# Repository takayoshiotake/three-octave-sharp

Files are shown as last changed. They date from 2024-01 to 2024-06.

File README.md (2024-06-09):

# Three Octave \#

[][cc-by-sa]

A 38-key (3-octave + 1) keyboard. Powered by [Vial](https://get.vial.today/) firmware.

This keyboard is based on a 60% column staggered keyboard like the HHKB, which omits the number and symbol keys to reduce the number of keys to 38.

## Layout

v0.3.0

**Layer 0**:

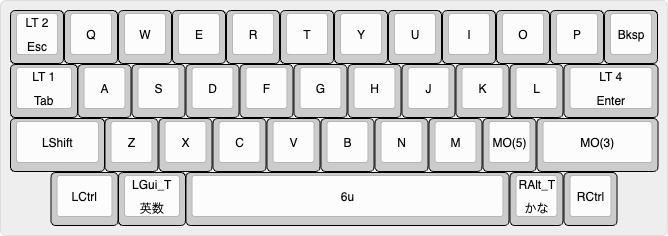
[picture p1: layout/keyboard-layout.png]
keyboard layout


MEMO: I couldn't figure out how to map keys to `fn` on macOS using Vial, so I am using Karabiner-Elements, a macOS app, to modify `right_control` to `fn`.

**Layer 1, 2**: arrows, symbols

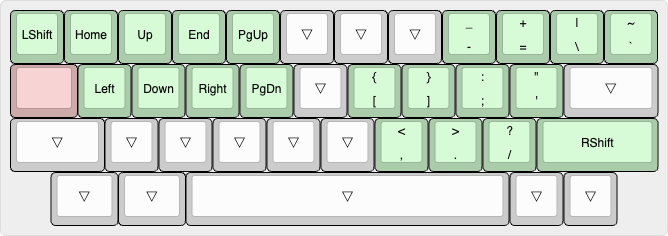
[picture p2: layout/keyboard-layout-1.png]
keyboard layout 1

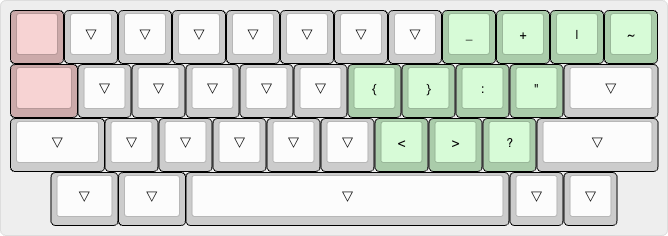
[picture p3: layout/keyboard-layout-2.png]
keyboard layout 2


**Layer 3, 4**: nums, symbols

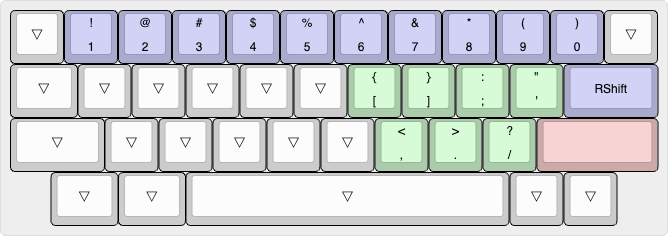
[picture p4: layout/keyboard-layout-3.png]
keyboard layout 3

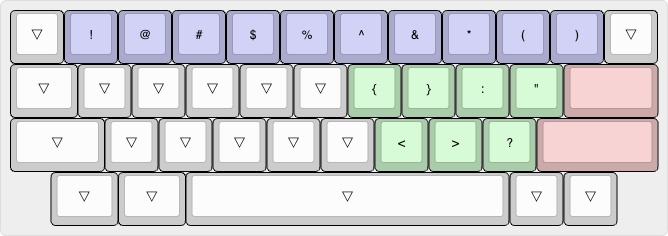
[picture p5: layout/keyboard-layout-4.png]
keyboard layout 4


**Layer 5**: fn

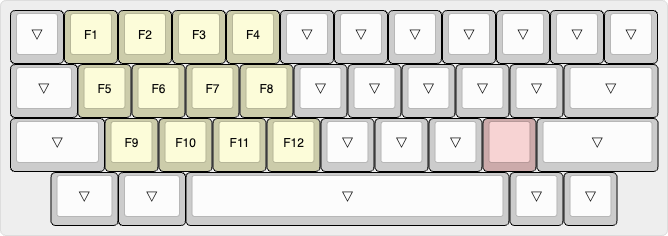
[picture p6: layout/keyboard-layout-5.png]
keyboard layout 5


**RAW data for Keyboard Layout Editor v0.15:**

📄 [keyboard-layout.rawdata.json](layout/keyboard-layout.rawdata.json)

```json
[{a:1},"LT 2\nEsc",{a:7},"Q","W","E","R","T","Y","U","I","O","P","Bksp"],
[{a:1,w:1.25},"LT 1\nTab",{a:7},"A","S","D","F","G","H","J","K","L",{a:1,w:1.75},"LT 4\nEnter"],
[{a:7,w:1.75},"LShift","Z","X","C","V","B","N","M","MO(5)",{w:2.25},"MO(3)"],
[{x:0.75,w:1.25},"LCtrl",{a:1,w:1.25},"LGui_T\n英数",{a:7,w:6},"6u",{a:1},"RAlt_T\nかな",{a:7},"RCtrl"],
```

- 🔗 [Keyboard Layout Editor](http://www.keyboard-layout-editor.com/)

## BOM

| Material | QTY | Note |
|-|-:|-|
| Three Octave Sharp PCBA | 1 | |
| Three Octave Sharp Case | 1 | |
| B-0204 | 4 | Screw M2 L4, Hirosugi |
| SIS-2039-05 | 4 | Washer d2 D3.9 t0.5, Hirosugi |
| LUW-0204-075 | 4 | Washer d2.2 D4 t0.075, Hirosugi |

### Three Octave Sharp PCBA

| Material | Symbol | QTY | Note |
|-|-|-:|-|
| Three Octave Sharp PCB | - | 1 | |
| 30pF 402 | C1, C2 | 2 | C1570 |
| 1uF 402 | C3, C4 | 2 | C52923 |
| 100nF 402 | C5-C14 | 10 | C307331 |
| 10uF 402 | C15, C16 | 2 | C15525 |
| HRO_TYPE-C-31-M-12 | J1 | 1 | C165948; USB Type-C Connector, Korean Hroparts Elec |
| 10KΩ 0402 | R1, R3 | 2 | C25744 |
| 1KΩ 0402 | R2, R4 | 2 | C11702 |
| 27Ω 0402 | R5, R6 | 2 | C352446 |
| 5.1KΩ 0402 | R7, R8 | 2 | C25905 |
| Hot_Swap_Socket_CPG151101S11 | SW1-SW38 | 38 | C5156480; How Swap Socket, Kailh |
| SKRPANE010 | SW_B1, SW_R1 | 2 | C470426; Tactile Switch, ALPS ALPINE |
| RP2040 | U1 | 1 | C2040; MCU, Raspberry Pi |
| W25Q64JVXGIQ | U2 | 1 | C2940195, 64M-bit Serial Flash, Winbond Electronics |
| AP2112K-3.3TRG1 | U3 | 1 | C51118, 3.3V Linear Voltage Regulators |
| X322512MSB4SI | Y1 | 1 | C9002, 12MHz 20pF Crystal Resonator, SMD-3225, Yangxing Tech |

📁 [production_data (for JLCPCB at 2024-01-25)](electronics/Three_Octave_Sharp/production/Three_Octave_Sharp_1.0.0_2024-01-25_19-34-58)

### Three Octave Sharp Case

WIP

## Schematic and PCB

📄 [Three_Octave_Sharp.kicad_sch](electronics/Three_Octave_Sharp/Three_Octave_Sharp.kicad_sch) (v1.0.0)

📄 [Three_Octave_Sharp.kicad_pcb](electronics/Three_Octave_Sharp/Three_Octave_Sharp.kicad_pcb) (v1.0.1)

schematic svg

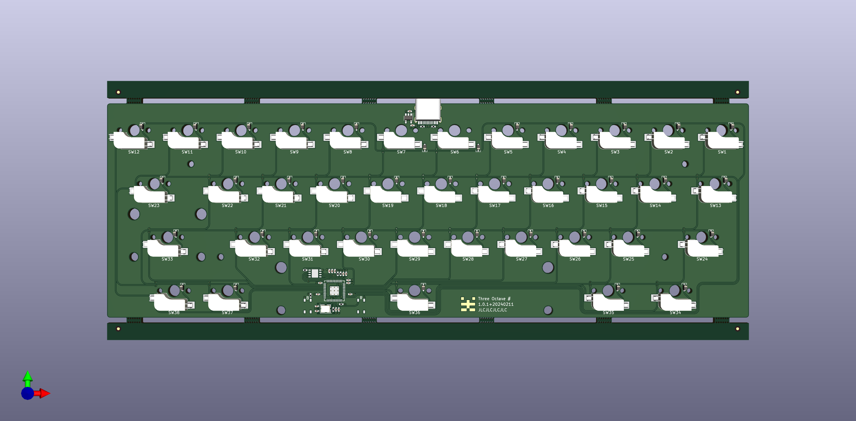
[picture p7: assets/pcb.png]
pcb png


### Key-matrix

| | C0 | C1 | C2 | C3 | C4 | C5 | C6 | C7 | C8 | C9 | C10 | C11 |
|----|---|---|---|----|----|----|----|----|----|---|---|-----|
| R0 | Esc | Q | W | E  | R  | T  | Y  | U  | I  | O | P | BS  |
| R1 | Tab | A | S | D  | F  | G  | H  | J  | K  | L | Return | |
| R2 | Shift | Z | X | C  | V  | B  | N  | M  | ,  | Shift | Opt | Fn  | 
| R3 | Ctrl  | Cmd  | Space | | | | | | | | | |

## Mechanics

The case also functions as a plate.

- 📄 [Three-Octave-Sharp-Case.FCStd](mechanics/Three-Octave-Sharp-Case.FCStd) (v1.0.3)
    - 📄 [Three-Octave-Sharp-Case-Top.step](mechanics/Three-Octave-Sharp-Case-Top.step)
    - 📄 [Three-Octave-Sharp-Case-Bottom.step](Three-Octave-Sharp-Case-Bottom.step)

<div style="display: grid; gap: 1px; grid-template: 'a0 a0 a0 a0' 'a2t a2t a2b a2b' 'a5t a5t a5b a5b' 'a1 a3 a4 a6';">
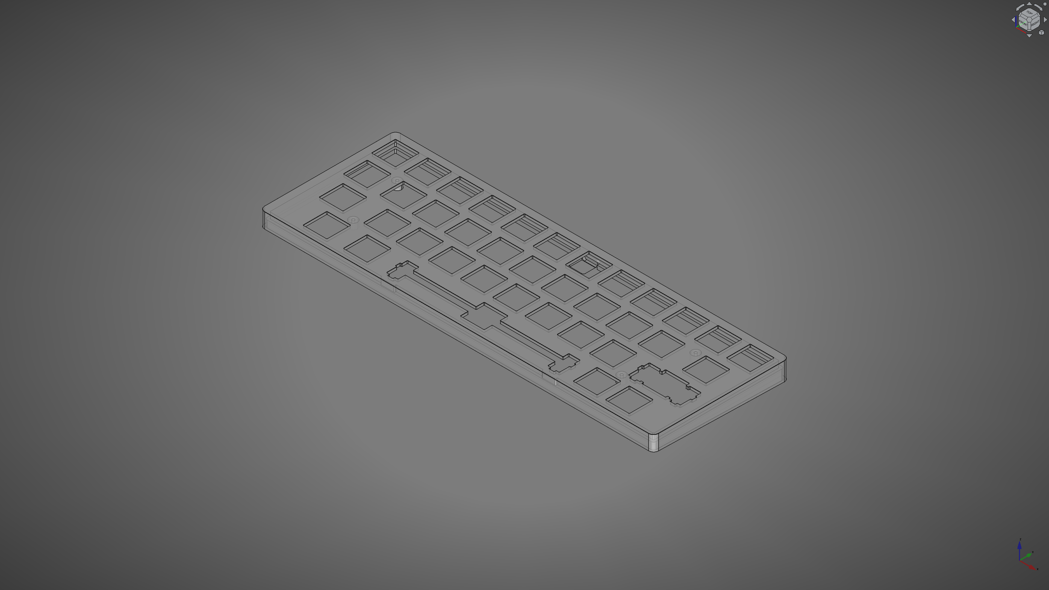
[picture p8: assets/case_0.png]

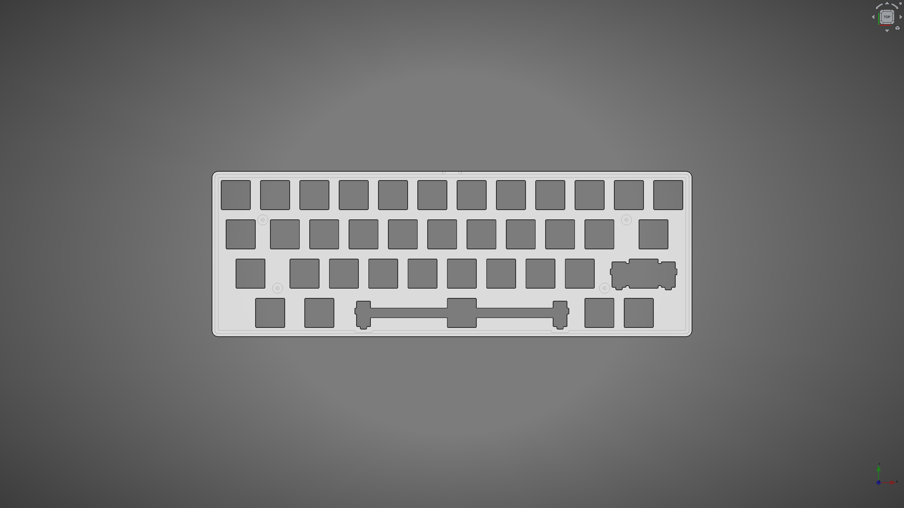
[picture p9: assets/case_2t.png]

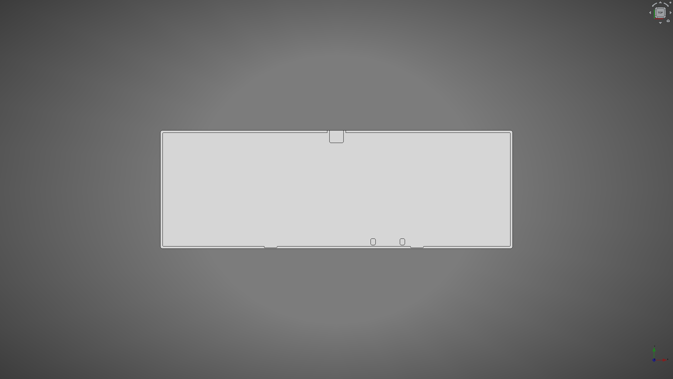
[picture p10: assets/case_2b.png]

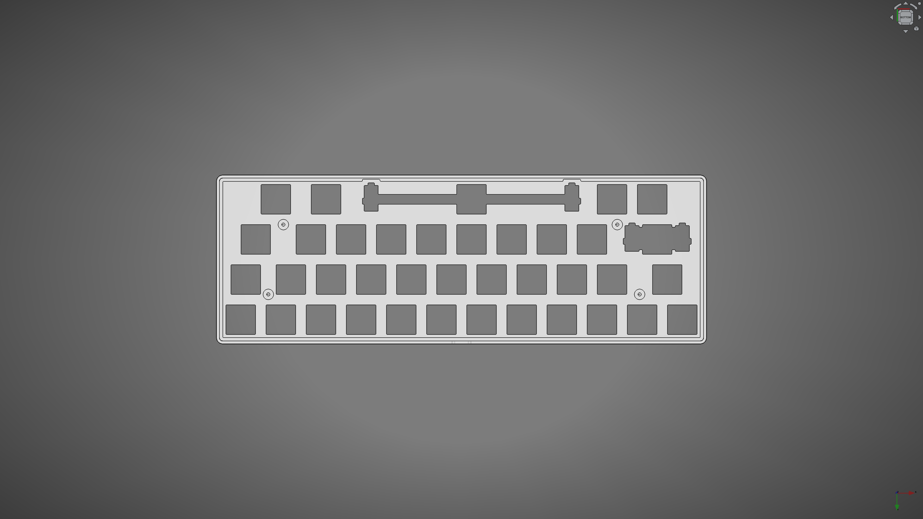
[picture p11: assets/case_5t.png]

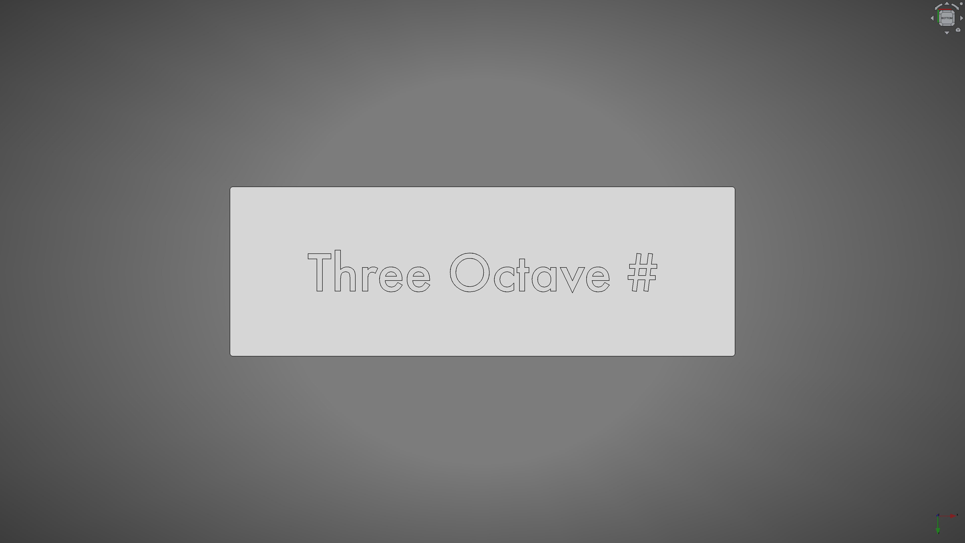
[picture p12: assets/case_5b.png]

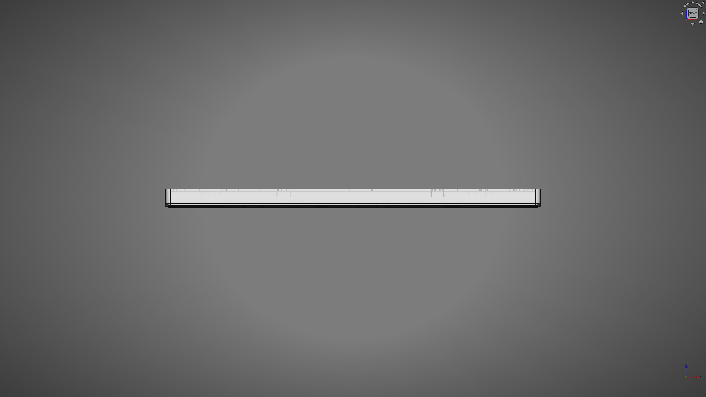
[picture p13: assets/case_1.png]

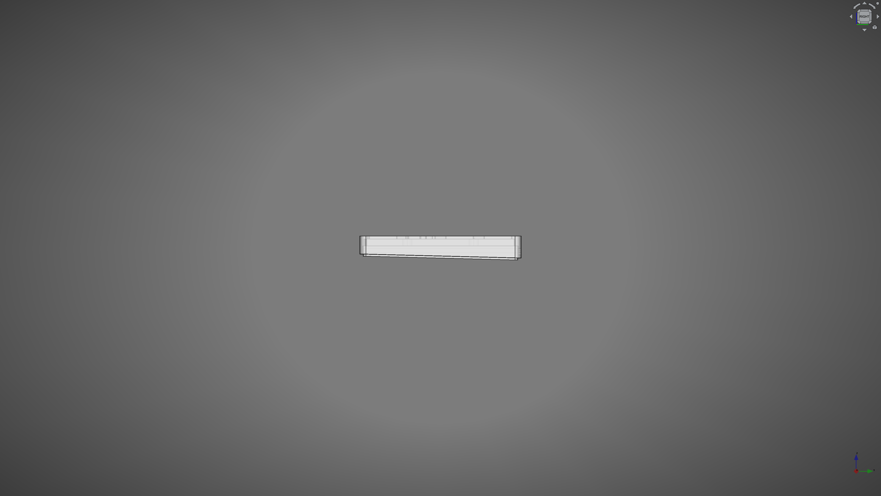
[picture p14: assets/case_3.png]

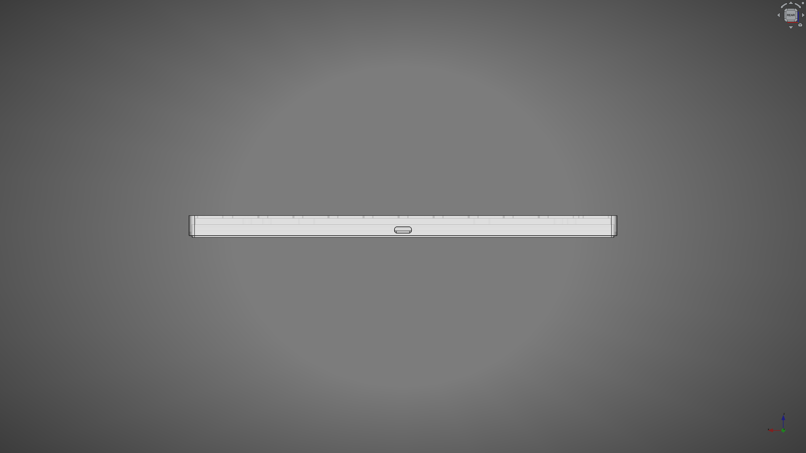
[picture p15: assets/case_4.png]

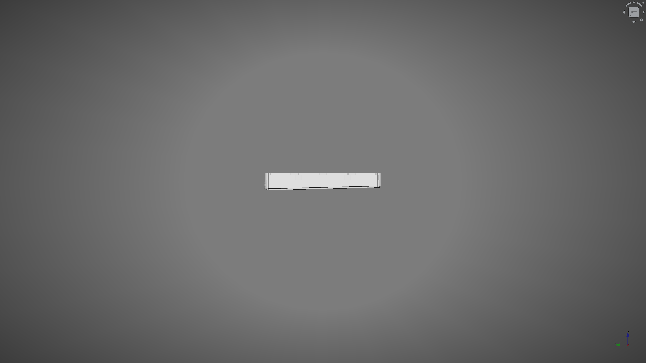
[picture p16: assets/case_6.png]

</div>

## Firmware

### Vial

- Built UF2
    - 📄 [takayoshiotake_three_octave_sharp_vial_20240407.uf2](vial-bin/takayoshiotake_three_octave_sharp_vial_20240407.uf2)
- Code
    - 🔗 <https://github.com/vial-kb/vial-qmk/tree/vial/keyboards/takayoshiotake/three_octave_sharp>
    - 🔗 <https://github.com/vial-kb/vial-qmk/tree/bbaed80505cf4ceaeb51d1e5fe79b23b22acf1a6>

See [vial-porting](vial-porting) for more details.

## License

This work is licensed under a
[Creative Commons Attribution-ShareAlike 4.0 International License][cc-by-sa].

[][cc-by-sa]

[cc-by-sa]: http://creativecommons.org/licenses/by-sa/4.0/
[cc-by-sa-image]: https://licensebuttons.net/l/by-sa/4.0/88x31.png
[cc-by-sa-shield]: https://img.shields.io/badge/license-CC%20BY--SA%204.0-lightgrey.svg

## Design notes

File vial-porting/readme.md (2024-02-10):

# Three Octave #

Three Octave #

Vial firmware for the Three Octave 40% keyboard. You can find other information including hardware design in the [GitHub repository](https://github.com/takayoshiotake/three-octave-sharp-38-key-keyboard).

Keyboard Maintainer: [takayoshiotake](https://github.com/takayoshiotake)

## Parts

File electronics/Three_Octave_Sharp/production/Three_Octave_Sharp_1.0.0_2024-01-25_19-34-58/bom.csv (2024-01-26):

Designator | Footprint | Quantity | Value | LCSC Part #
C1, C2 | 0402 | 2 | 30pF | C1570
C10, C11, C12, C13, C14, C5, C6, C7, C8, C9 | 0402 | 10 | 0.1uF | C307331
C15, C16 | 0402 | 2 | 10uF | C15525
C3, C4 | 0402 | 2 | 1uF | C52923
D1, D10, D11, D12, D13, D14, D15, D16, D17, D18, D19, D2, D20, D21, D22, D23, D24, D25, D26, D27, D28, D29, D3, D30, D31, D32, D33, D34, D35, D36, D37, D38, D4, D5, D6, D7, D8, D9 | D_SOD-323F | 38 | 1N4148WS | C2128
J1 | HRO_TYPE-C-31-M-12 | 1 | HRO_TYPE-C-31-M-12 | C165948
R1, R3 | 0402 | 2 | 10K | C25744
R2, R4 | 0402 | 2 | 1K | C11702
R5, R6 | 0402 | 2 | 27 | C25100
R7, R8 | 0402 | 2 | 5.1K | C25905
SW1 | Hot_Swap_Socket_CPG151101S11 | 1 | Key Tab | C5156480
SW10 | Hot_Swap_Socket_CPG151101S11 | 1 | Key O | C5156480
SW11 | Hot_Swap_Socket_CPG151101S11 | 1 | Key P | C5156480
SW12 | Hot_Swap_Socket_CPG151101S11 | 1 | Key BS | C5156480
SW13 | Hot_Swap_Socket_CPG151101S11 | 1 | Key Caps | C5156480
SW14 | Hot_Swap_Socket_CPG151101S11 | 1 | Key A | C5156480
SW15 | Hot_Swap_Socket_CPG151101S11 | 1 | Key S | C5156480
SW16 | Hot_Swap_Socket_CPG151101S11 | 1 | Key D | C5156480
SW17 | Hot_Swap_Socket_CPG151101S11 | 1 | Key F | C5156480
SW18 | Hot_Swap_Socket_CPG151101S11 | 1 | Key G | C5156480
SW19 | Hot_Swap_Socket_CPG151101S11 | 1 | Key H | C5156480
SW2 | Hot_Swap_Socket_CPG151101S11 | 1 | Key Q | C5156480
SW20 | Hot_Swap_Socket_CPG151101S11 | 1 | Key J | C5156480
SW21 | Hot_Swap_Socket_CPG151101S11 | 1 | Key K | C5156480
SW22 | Hot_Swap_Socket_CPG151101S11 | 1 | Key L | C5156480
SW23 | Hot_Swap_Socket_CPG151101S11 | 1 | Key Return | C5156480
SW24, SW33 | Hot_Swap_Socket_CPG151101S11 | 2 | Key Shift | C5156480
SW25 | Hot_Swap_Socket_CPG151101S11 | 1 | Key Z | C5156480
SW26 | Hot_Swap_Socket_CPG151101S11 | 1 | Key X | C5156480
SW27 | Hot_Swap_Socket_CPG151101S11 | 1 | Key C | C5156480
SW28 | Hot_Swap_Socket_CPG151101S11 | 1 | Key V | C5156480
SW29 | Hot_Swap_Socket_CPG151101S11 | 1 | Key B | C5156480
SW3 | Hot_Swap_Socket_CPG151101S11 | 1 | Key W | C5156480
SW30 | Hot_Swap_Socket_CPG151101S11 | 1 | Key N | C5156480
SW31 | Hot_Swap_Socket_CPG151101S11 | 1 | Key M | C5156480
SW32 | Hot_Swap_Socket_CPG151101S11 | 1 | Key , | C5156480
SW34 | Hot_Swap_Socket_CPG151101S11 | 1 | Key Ctrl | C5156480
SW35 | Hot_Swap_Socket_CPG151101S11 | 1 | Key Cmd | C5156480
SW36 | Hot_Swap_Socket_CPG151101S11 | 1 | Key Space | C5156480
SW37 | Hot_Swap_Socket_CPG151101S11 | 1 | Key Opt | C5156480
SW38 | Hot_Swap_Socket_CPG151101S11 | 1 | Key Fn | C5156480
SW4 | Hot_Swap_Socket_CPG151101S11 | 1 | Key E | C5156480
SW5 | Hot_Swap_Socket_CPG151101S11 | 1 | Key R | C5156480
SW6 | Hot_Swap_Socket_CPG151101S11 | 1 | Key T | C5156480
SW7 | Hot_Swap_Socket_CPG151101S11 | 1 | Key Y | C5156480
SW8 | Hot_Swap_Socket_CPG151101S11 | 1 | Key U | C5156480
SW9 | Hot_Swap_Socket_CPG151101S11 | 1 | Key I | C5156480
SW_B1, SW_R1 | Tactile_Switch_SKRP_Series | 2 | Alps_Alpine_SKRP | C470426
U1 | RP2040_QFN-56 | 1 | Raspberry_Pi_RP2040 | C2040
U2 | XSON-8-EP_4x4mm | 1 | W25Q64JVXGIQ | C2940195
U3 | SOT-23-5 | 1 | AP2112K-3.3 | C51118
Y1 | Crystal_SMD_3225-4Pin_3.2x2.5mm | 1 | 12MHz | C9002

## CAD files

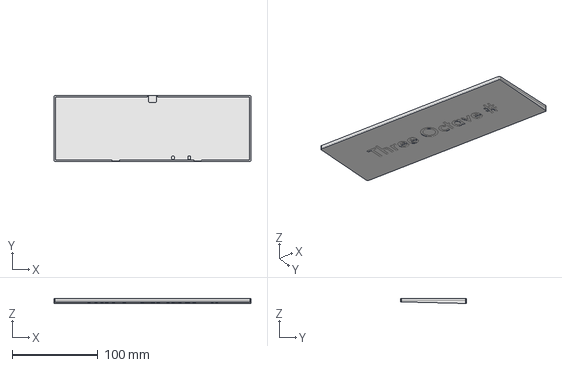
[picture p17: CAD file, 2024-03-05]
mechanics/Three-Octave-Sharp-Case.FCStd
229.3 x 76.9 x 5.76 mm

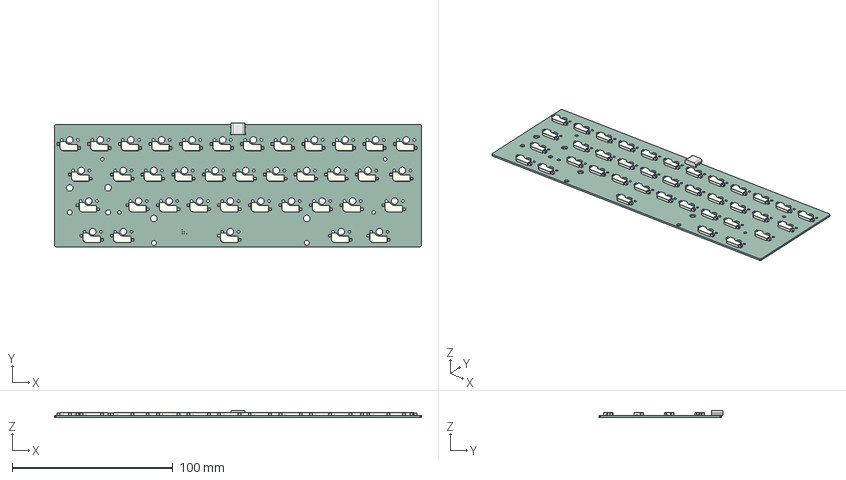
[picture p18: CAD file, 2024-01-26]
mechanics/pcba.step
228.6 x 77.2 x 4.45 mm
Hot_Swap_Socket_CPG151101S11 x 38
Three_Octave_Sharp PCB

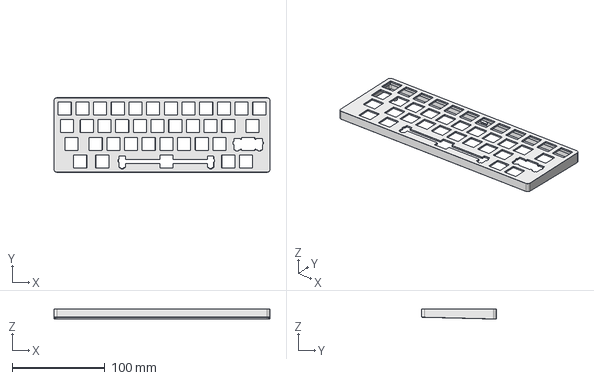
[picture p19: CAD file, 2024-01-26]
mechanics/Three-Octave-Sharp-Case-Top.step
232.7 x 80.2 x 11.0 mm

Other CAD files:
mechanics/Three-Octave-Sharp-Case-Bottom.step
mechanics/frame-spacebar-2u.FCStd
mechanics/frame-spacebar-6u.FCStd

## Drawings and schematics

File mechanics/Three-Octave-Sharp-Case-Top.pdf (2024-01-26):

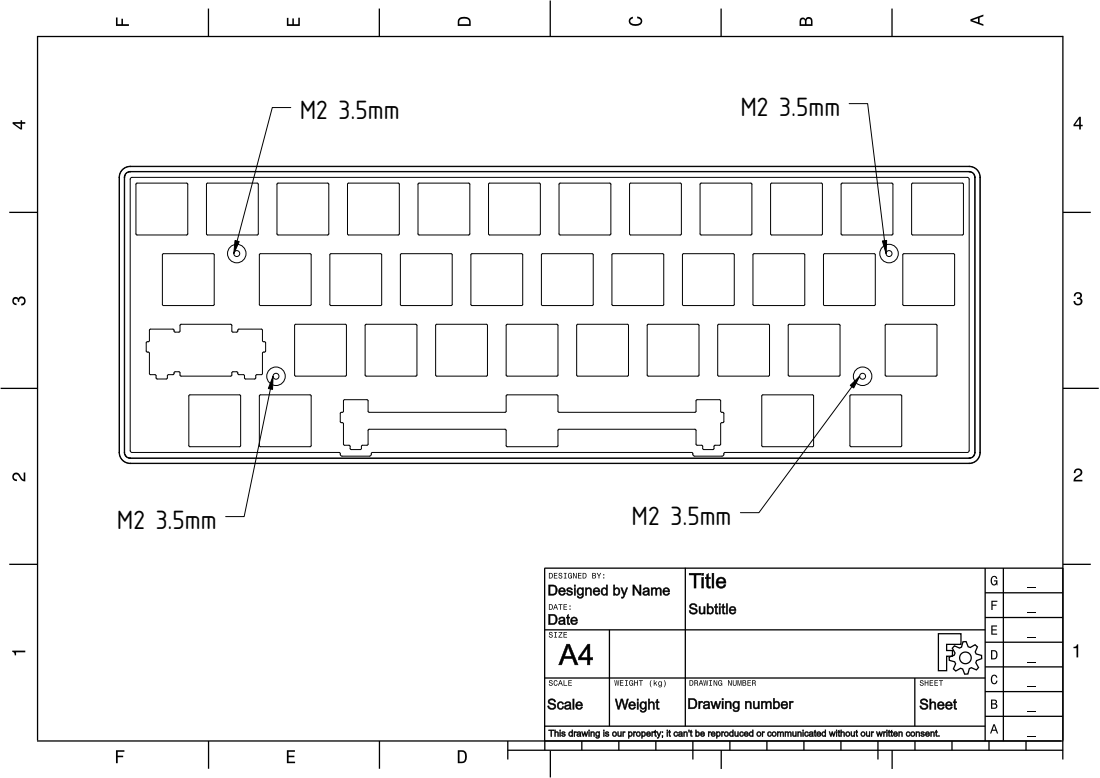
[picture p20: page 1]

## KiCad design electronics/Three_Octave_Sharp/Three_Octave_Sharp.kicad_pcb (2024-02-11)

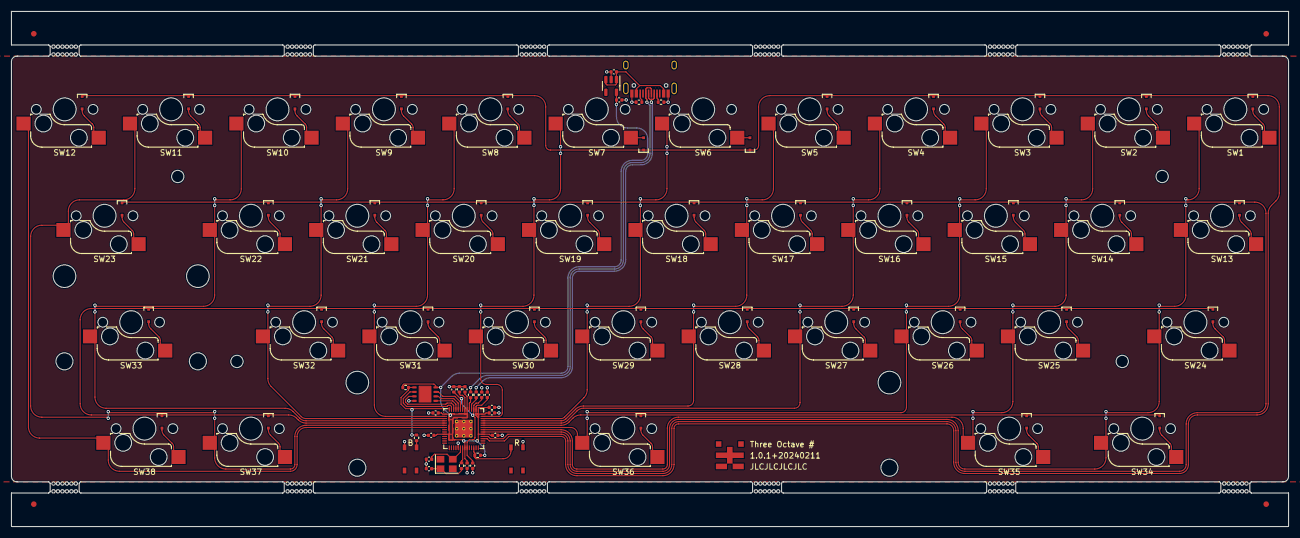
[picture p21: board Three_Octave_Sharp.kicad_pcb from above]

Board: 2 copper layers, 228.6 x 92.2 mm, 107 parts (0 on the bottom side), 75 nets.

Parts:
C1, C2: 30pF; C_0402_1005Metric
C3, C4: 1uF; C_0402_1005Metric
C5, C6, C7, C8, C9, C10, C11, C12, C13, C14: 0.1uF; C_0402_1005Metric
C15, C16: 10uF; C_0402_1005Metric
D1, D2, D3, D4, D5, D6, D7, D8, D9, D10, D11, D12, D13, D14, D15, D16, D17, D18, D19, D20, D21, D22, D23, D24, D25, D26, D27, D28, D29, D30, D31, D32, D33, D34, D35, D36, D37, D38: 1N4148WS; D_SOD-323F
J1: HRO_TYPE-C-31-M-12
R1, R3: 10K; R_0402_1005Metric
R2, R4: 1K; R_0402_1005Metric
R5, R6: 27; R_0402_1005Metric
R7, R8: 5.1K; R_0402_1005Metric
SW1: Key Tab; Hot_Swap_Socket_CPG151101S11
SW2: Key Q; Hot_Swap_Socket_CPG151101S11
SW3: Key W; Hot_Swap_Socket_CPG151101S11
SW4: Key E; Hot_Swap_Socket_CPG151101S11
SW5: Key R; Hot_Swap_Socket_CPG151101S11
SW6: Key T; Hot_Swap_Socket_CPG151101S11
SW7: Key Y; Hot_Swap_Socket_CPG151101S11
SW8: Key U; Hot_Swap_Socket_CPG151101S11
SW9: Key I; Hot_Swap_Socket_CPG151101S11
SW10: Key O; Hot_Swap_Socket_CPG151101S11
SW11: Key P; Hot_Swap_Socket_CPG151101S11
SW12: Key BS; Hot_Swap_Socket_CPG151101S11
SW13: Key Caps; Hot_Swap_Socket_CPG151101S11
SW14: Key A; Hot_Swap_Socket_CPG151101S11
SW15: Key S; Hot_Swap_Socket_CPG151101S11
SW16: Key D; Hot_Swap_Socket_CPG151101S11
SW17: Key F; Hot_Swap_Socket_CPG151101S11
SW18: Key G; Hot_Swap_Socket_CPG151101S11
SW19: Key H; Hot_Swap_Socket_CPG151101S11
SW20: Key J; Hot_Swap_Socket_CPG151101S11
SW21: Key K; Hot_Swap_Socket_CPG151101S11
SW22: Key L; Hot_Swap_Socket_CPG151101S11
SW23: Key Return; Hot_Swap_Socket_CPG151101S11
SW24, SW33: Key Shift; Hot_Swap_Socket_CPG151101S11
SW25: Key Z; Hot_Swap_Socket_CPG151101S11
SW26: Key X; Hot_Swap_Socket_CPG151101S11
SW27: Key C; Hot_Swap_Socket_CPG151101S11
SW28: Key V; Hot_Swap_Socket_CPG151101S11
SW29: Key B; Hot_Swap_Socket_CPG151101S11
SW30: Key N; Hot_Swap_Socket_CPG151101S11
SW31: Key M; Hot_Swap_Socket_CPG151101S11
SW32: Key ,; Hot_Swap_Socket_CPG151101S11
SW34: Key Ctrl; Hot_Swap_Socket_CPG151101S11
SW35: Key Cmd; Hot_Swap_Socket_CPG151101S11
SW36: Key Space; Hot_Swap_Socket_CPG151101S11
SW37: Key Opt; Hot_Swap_Socket_CPG151101S11
SW38: Key Fn; Hot_Swap_Socket_CPG151101S11
SW_B1: Alps_Alpine_SKRP; Tactile_Switch_SKRP_Series
SW_R1: Alps_Alpine_SKRP; Tactile_Switch_SKRP_Series
U1: Raspberry_Pi_RP2040; RP2040_QFN-56
U2: W25Q64JVXGIQ; XSON-8-EP_4x4mm
U3: AP2112K-3.3; SOT-23-5
Y1: 12MHz; Crystal_SMD_3225-4Pin_3.2x2.5mm

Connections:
+1V1: C4.1, C13.1, C14.1, U1.23 (DVDD), U1.45 (VREG_VOUT), U1.50 (DVDD)
+3V3: C3.1, C5.1, C6.1, C7.1, C8.1, C9.1, C10.1, C11.1, C12.1, C16.1, R1.1, R3.1, U1.1 (IOVDD), U1.10 (IOVDD), U1.22 (IOVDD), U1.33 (IOVDD), U1.42 (IOVDD), U1.43 (ADC_AVDD), U1.44 (VREG_VIN), U1.48 (USB_VDD), U1.49 (IOVDD), U2.8 (VCC), U3.5 (VOUT)
+5V: C15.1, J1.A4/B9 (VBUS), J1.A9/B4 (VBUS), U3.1 (VIN), U3.3 (EN)
COL0: SW1.2, SW13.2, SW24.2, SW34.2, U1.34 (GPIO22)
COL1: SW2.2, SW14.2, SW25.2, SW35.2, U1.35 (GPIO23)
COL2: SW3.2, SW15.2, SW26.2, SW36.2, U1.36 (GPIO24)
COL3: SW4.2, SW16.2, SW27.2, U1.38 (GPIO26/ADC0)
COL4: SW5.2, SW17.2, SW28.2, U1.39 (GPIO27/ADC1)
COL5: SW6.2, SW18.2, SW29.2, U1.40 (GPIO28/ADC2)
COL6: SW7.2, SW19.2, SW30.2, U1.41 (GPIO29/ADC3)
COL7: SW8.2, SW20.2, SW31.2, U1.2 (GPIO0)
COL8: SW9.2, SW21.2, SW32.2, U1.3 (GPIO1)
COL9: SW10.2, SW22.2, SW33.2, U1.4 (GPIO2)
COL10: SW11.2, SW23.2, SW37.2, U1.6 (GPIO4)
COL11: SW12.2, SW38.2, U1.7 (GPIO5)
D+: R5.1, U1.47 (USB_DP)
D-: R6.1, U1.46 (USB_DM)
GND: C1.2, C2.2, C3.2, C4.2, C5.2, C6.2, C7.2, C8.2, C9.2, C10.2, C11.2, C12.2, C13.2, C14.2, C15.2, C16.2, J1.A1/B12 (GND), J1.A12/B1 (GND), R7.2, R8.2, SW_B1.3, SW_R1.1, U1.19 (TESTEN), U1.57 (GND), U2.4 (GND), U3.2 (GND)
unnamed: C2.1, R2.2, Y1.1
unnamed: D1.2 (A), SW1.1
unnamed: D2.2 (A), SW2.1
unnamed: D3.2 (A), SW3.1
unnamed: D4.2 (A), SW4.1
unnamed: D5.2 (A), SW5.1
unnamed: D6.2 (A), SW6.1
unnamed: D7.2 (A), SW7.1
unnamed: D8.2 (A), SW8.1
unnamed: D9.2 (A), SW9.1
unnamed: D10.2 (A), SW10.1
unnamed: D11.2 (A), SW11.1
unnamed: D12.2 (A), SW12.1
unnamed: D13.2 (A), SW13.1
unnamed: D14.2 (A), SW14.1
unnamed: D15.2 (A), SW15.1
unnamed: D16.2 (A), SW16.1
unnamed: D17.2 (A), SW17.1
unnamed: D18.2 (A), SW18.1
unnamed: D19.2 (A), SW19.1
unnamed: D20.2 (A), SW20.1
unnamed: D21.2 (A), SW21.1
unnamed: D22.2 (A), SW22.1
unnamed: D23.2 (A), SW23.1
unnamed: D24.2 (A), SW24.1
unnamed: D25.2 (A), SW25.1
unnamed: D26.2 (A), SW26.1
unnamed: D27.2 (A), SW27.1
unnamed: D28.2 (A), SW28.1
unnamed: D29.2 (A), SW29.1
unnamed: D30.2 (A), SW30.1
unnamed: D31.2 (A), SW31.1
unnamed: D32.2 (A), SW32.1
unnamed: D33.2 (A), SW33.1
unnamed: D34.2 (A), SW34.1
unnamed: D35.2 (A), SW35.1
unnamed: D36.2 (A), SW36.1
unnamed: D37.2 (A), SW37.1
unnamed: D38.2 (A), SW38.1
unnamed: J1.A5 (CC1), R8.1
unnamed: J1.B5 (CC2), R7.1
unnamed: J1.A6 (D+), J1.B6 (D+), R5.2
unnamed: J1.A7 (D-), J1.B7 (D-), R6.2
unnamed: R4.2, SW_B1.1
unnamed: U1.52 (QSPI_SCLK), U2.6 (CLK)
unnamed: U1.53 (QSPI_SD0), U2.5 (DI(IO0))
unnamed: U1.55 (QSPI_SD1), U2.2 (DO(IO1))
unnamed: U1.54 (QSPI_SD2), U2.3 (IO2)
unnamed: U1.51 (QSPI_SD3), U2.7 (IO3)
unnamed: R1.2, SW_R1.3, U1.26 (RUN)
unnamed: C1.1, U1.20 (XIN), Y1.3
unnamed: R2.1, U1.21 (XOUT)
QSPI_SS_N: R3.2, R4.1, U1.56 (QSPI_SS_N), U2.1 (~CS)
ROW0: D1.1 (K), D2.1 (K), D3.1 (K), D4.1 (K), D5.1 (K), D6.1 (K), D7.1 (K), D8.1 (K), D9.1 (K), D10.1 (K), D11.1 (K), D12.1 (K), U1.31 (GPIO20)
ROW1: D13.1 (K), D14.1 (K), D15.1 (K), D16.1 (K), D17.1 (K), D18.1 (K), D19.1 (K), D20.1 (K), D21.1 (K), D22.1 (K), D23.1 (K), U1.32 (GPIO21)
ROW2: D24.1 (K), D25.1 (K), D26.1 (K), D27.1 (K), D28.1 (K), D29.1 (K), D30.1 (K), D31.1 (K), D32.1 (K), D33.1 (K), D37.1 (K), D38.1 (K), U1.5 (GPIO3)
ROW3: D34.1 (K), D35.1 (K), D36.1 (K), U1.37 (GPIO25)

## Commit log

2024-01-06 Add KiCad project copied from Five Octave
    Rename it to "Three Octave #" and add the 6u stabilizer footprint
    [Three_Octave_Sharp.kicad_pcb, Three_Octave_Sharp.kicad_sch]
2024-01-07 Remove meaningless wire
    [Three_Octave_Sharp.kicad_sch]
2024-01-07 Add schematic and PCB design copied from Five Octave
    [Three_Octave_Sharp.kicad_pcb, Three_Octave_Sharp.kicad_sch]
2024-01-07 Layout keys on PCB
    [Three_Octave_Sharp.kicad_pcb, Three_Octave_Sharp.kicad_sch]
2024-01-07 WIP: Update schematic and PCB design
    [Three_Octave_Sharp.kicad_pcb, Three_Octave_Sharp.kicad_sch]
2024-01-09 WIP: Update PCB design
    [Three_Octave_Sharp.kicad_pcb]
2024-01-16 Change paper size
    [Three_Octave_Sharp.kicad_pcb]
2024-01-19 Add 3D shape for USB-C connector
    [Three_Octave_Sharp.kicad_pcb]
2024-01-20 Change PCB thickness to 1.2 mm
    [Three_Octave_Sharp.kicad_pcb]
2024-01-20 Fix stabilizer-2u footprint
    [Three_Octave_Sharp.kicad_pcb]
2024-01-20 Fix stabilizer footprint (2u, 6u)
    [Three_Octave_Sharp.kicad_pcb]
2024-01-20 WIP: Add case design
    [Three-Octave-Sharp-Case.FCStd, frame-spacebar-2u.FCStd, frame-spacebar-6u.FCStd]
2024-01-22 WIP: Update case design
    [Three-Octave-Sharp-Case.FCStd, Three_Octave_Sharp.kicad_pcb, pcb.step]
2024-01-24 WIP: Update 3d design
    [Three-Octave-Sharp-Case.FCStd, Three_Octave_Sharp.kicad_pcb, pcba.step]
2024-01-25 Change resistor part # for JLCPCB
    [Three_Octave_Sharp.kicad_pcb, Three_Octave_Sharp.kicad_sch]
2024-01-25 Add edge rails and fiducials
    [Three_Octave_Sharp_Fiducials.kicad_pcb]
2024-01-25 Update PCB version number
    [Three_Octave_Sharp.kicad_pcb, Three_Octave_Sharp.kicad_sch]
2024-01-26 Add production files
    [bom.csv, designators.csv, positions.csv]
2024-02-11 Fix pcb outline (0.005 mm)
    [Three_Octave_Sharp.kicad_pcb]
2024-02-11 V up
    [Three_Octave_Sharp.kicad_pcb]
2024-02-11 Fix case-bottom for reset and boot switches
    [Three-Octave-Sharp-Case-Bottom.step, Three-Octave-Sharp-Case.FCStd]
2024-02-11 Improve connectors for edge rails
    [Three_Octave_Sharp.kicad_pcb]
2024-02-27 Modify case-bottom for CNC
    [Three-Octave-Sharp-Case-Bottom.step, Three-Octave-Sharp-Case.FCStd]
2024-03-05 Modify case-bottom logo
    [Three-Octave-Sharp-Case-Bottom.step, Three-Octave-Sharp-Case.FCStd]
2024-06-08 Add BOM (WIP)
2024-06-09 Add case images
2024-06-09 Reorder case images
    Improve when grid styles are disabled

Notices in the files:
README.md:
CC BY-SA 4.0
